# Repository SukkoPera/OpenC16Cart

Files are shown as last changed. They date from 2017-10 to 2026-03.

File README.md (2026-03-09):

# OpenC16Cart





OpenC16Cart is an Open Hardware 8/16/32/64 KB Cartridge for the Commodore 16, Plus/4 and the rest of the Commodore 264 family.

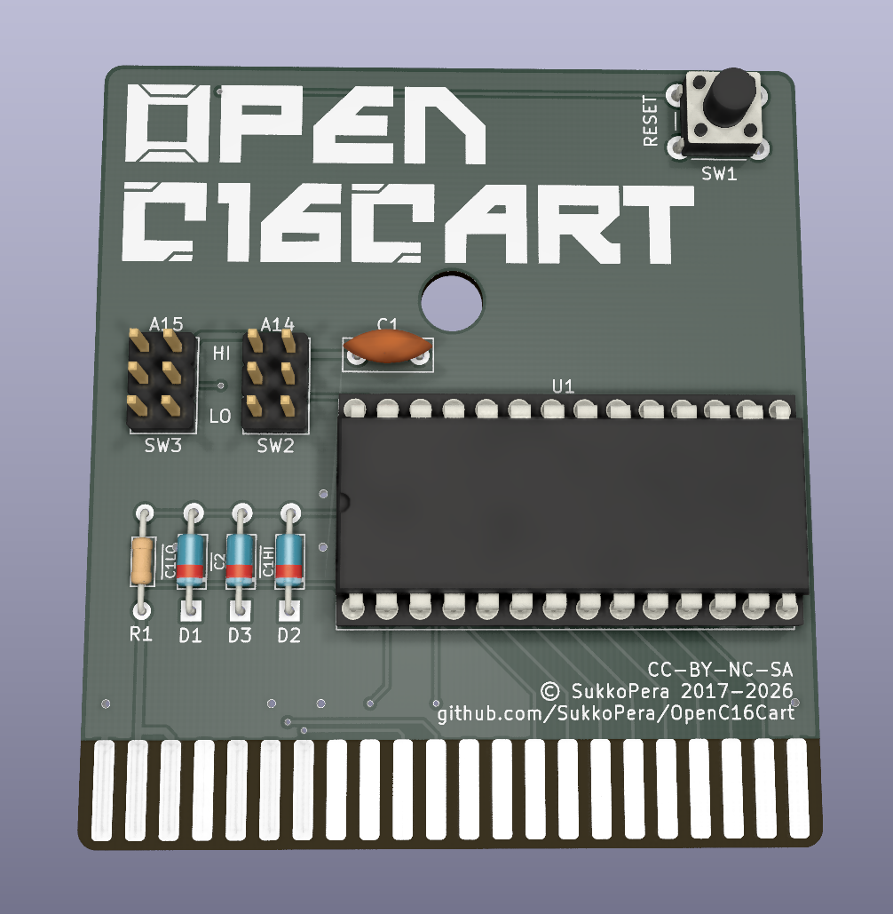
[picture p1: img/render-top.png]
Board


## Summary
> Like all the other Commodore 8-bit systems, the Plus/4 had a cartridge port for ROM-based software. Because the computer did not do well in the marketplace, however, very few were released. - Bo Zimmerman

One day I decided to fix my old Commodore 16. I found out about [Diag264](http://www.inchocks.co.uk/commodore/Diag264/) and, since I knew that C16 carts weren't exactly common (to this very day of 2026 I have never seen one "in the flesh"!), I was shocked to learn that [people are deliberately destroying genuine carts to use them as donors to build a Diag264](http://blog.tynemouthsoftware.co.uk/2014/03/commodore-264-c16-and-plus-4-diagnostic.html).

Since I had already built an [Open Hardware cartridge for the Commodore 64](https://github.com/SukkoPera/OpenC64Cart), I thought that one for the C16 could not be much different, and so this project was born.

Since I did not own a cartridge, I set out to find images of PCBs of real cartridges on the Net, only to find out that those are rare as well. In the end I found a couple of [top](https://github.com/SukkoPera/OpenC16Cart/blob/master/doc/inspiration-top.jpg)+[bottom](https://github.com/SukkoPera/OpenC16Cart/blob/master/doc/inspiration-bottom.jpg) images, and started to reverse engineer the design from those. With the help of [some service manuals](http://www.zimmers.net/anonftp/pub/cbm/schematics/computers/plus4/index.html), I came up with OpenC16Cart. I then expanded it to have the ability of using bigger (E(E))PROMs which could store multiple ROM images.

With V5, I even added the possibility of having a single-EEPROM 64 kB cartridge spanning both the C1 and C2 slots.

> [!IMPORTANT]
> V5 is a 44-pin cartridge. It is not compatible with a stock C16/+4. To use it, you will need a [Plus4MultiExpander](https://github.com/SukkoPera/Plus4MultiExpander) [^v4].

V5 was designed in order to fit into [TFW8b's Stumpy Cases](https://www.tfw8b.com/product/commodore-c64-stumpy-cartridge-case/), but the actual fitting has never been checked.

## Configuration
As of V5, OpenC16Cart might work in different modes. Ideally, the cartridge is used with a 64 kb EEPROM, in which case the following configurations will be available:

### 16 kB Mode
In 16 kB mode, you get 4 banks, which can be selected through appropriate placement of the SW2 and SW3 jumpers:

|Bank|SW3|SW2|ROM Area |
|----|---|---|---|
|0 |LO |LO |$0000-$3fff|
|1 |LO |HI |$4000-$7fff|
|2 |HI |LO |$8000-$bfff|
|3 |HI |HI |$c000-$ffff|

Note that the cartridge will respond to all C1 and C2 low/high slots. If this is unwanted, cut open JP1/2/3 accordingly (or do not mount D1/2/3). Also note there is no way to respond to a single C2 slot.

### 32 kB Mode
In 32 kB mode, SW2 must be placed in the `DIR` position and 2 banks will be available through manipulation of SW3:

|Bank|SW3|ROM Area |
|----|---|---|
|0 |LO |Low ROM: $0000-$3fff<br/>High ROM: $4000-$7fff|
|1 |HI |Low ROM: $8000-$bfff<br/>High ROM: $c000-$ffff|

As in 16 kB mode, you might want to play with the jumpers or diodes.

### 64 kB Mode
In 64 kB mode, both SW2 and SW3 must be placed in the `DIR` position and, obviously, only a single bank will be available.

|Bank|ROM Area |
|----|---|
|0 |C2 Low ROM: $0000-$3fff<br/>C2 High ROM: $4000-$7fff<br>C1 Low ROM: $8000-$bfff<br/>C1 High ROM: $c000-$ffff|

Note that **C2 goes first**.

## Releases
If you want to get this board produced, you are recommended to get [the latest release](https://github.com/SukkoPera/OpenC16Cart/releases) rather than the current git version, as the latter might be under development and is not guaranteed to be working.

Every release is accompanied by its Bill Of Materials (BOM) file and any relevant notes about it, which you are recommended to read carefully.

**I am not providing ready-to-use gerber files**. If all you want is **to get boards made, I would really appreciate if you did so [in a way that supports the project](#support-the-project)**.

## License
The OpenC16Cart documentation, including the design itself, is copyright &copy; SukkoPera 2019-2026 and is licensed under the [Creative Commons Attribution-NonCommercial-ShareAlike 4.0 International License](https://creativecommons.org/licenses/by-nc-sa/4.0/).

This documentation is distributed *as is* and WITHOUT ANY EXPRESS OR IMPLIED WARRANTIES whatsoever with respect to its functionality, operability or use, including, without limitation, any implied warranties OF MERCHANTABILITY, SATISFACTORY QUALITY, FITNESS FOR A PARTICULAR PURPOSE or infringement. We expressly disclaim any liability whatsoever for any direct, indirect, consequential, incidental or special damages, including, without limitation, lost revenues, lost profits, losses resulting from business interruption or loss of data, regardless of the form of action or legal theory under which the liability may be asserted, even if advised of the possibility or likelihood of such damages.

## Support the Project
If you want to get some boards manufactured, you can get them from PCBWay through this link:

PCB from PCBWay (https://www.pcbway.com/project/shareproject/OpenC16Cart_V5_Open_Hardware_8_16_32_Kb_Cartridge_for_the_Commodore_16_116_an_705564ed.html)

You get my gratitude and cheap, professionally-made and good quality PCBs, I get some credit that will help with this and [other projects](https://www.pcbway.com/project/member/shareproject/?bmbid=41100). You won't even have to worry about the various PCB options, it's all pre-configured for you!

Also, if you still have to register, [you can use this link](https://www.pcbway.com/setinvite.aspx?inviteid=41100) to get some bonus initial credit (and yield me some more).

You can also buy me a coffee if you want:



[^v4]: Although this *might* be amended at some point, that's why there currently is no V4, it was reserved for that.

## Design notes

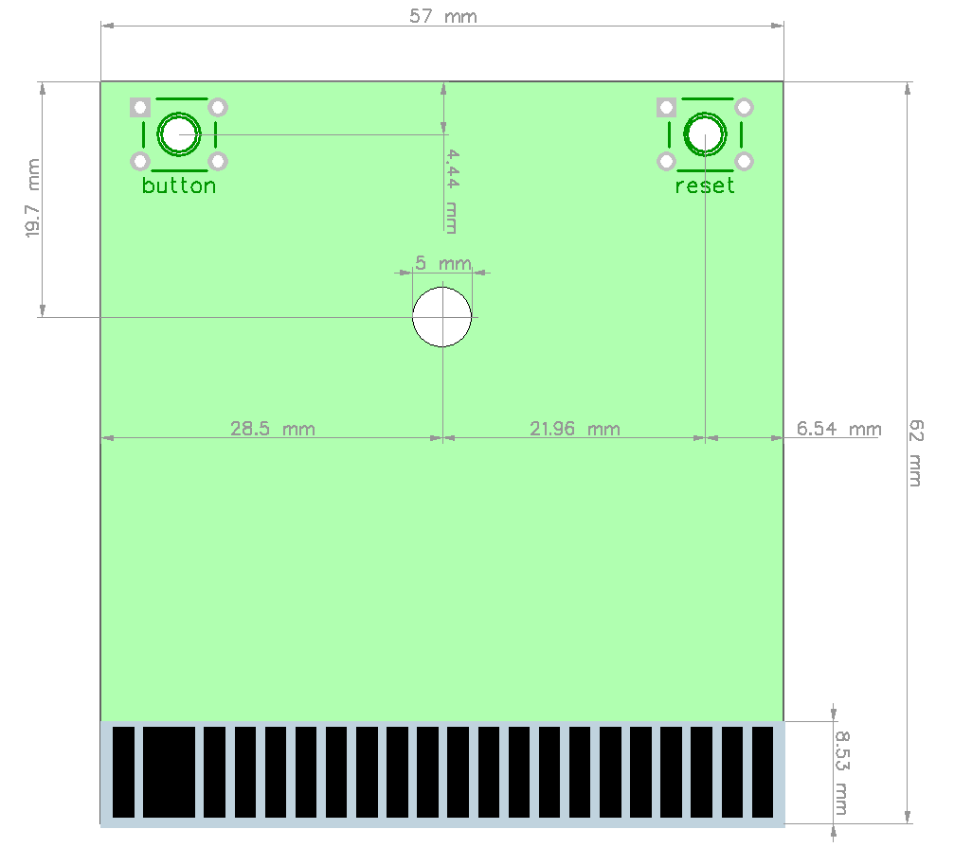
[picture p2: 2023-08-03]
doc/stumpy_case.png

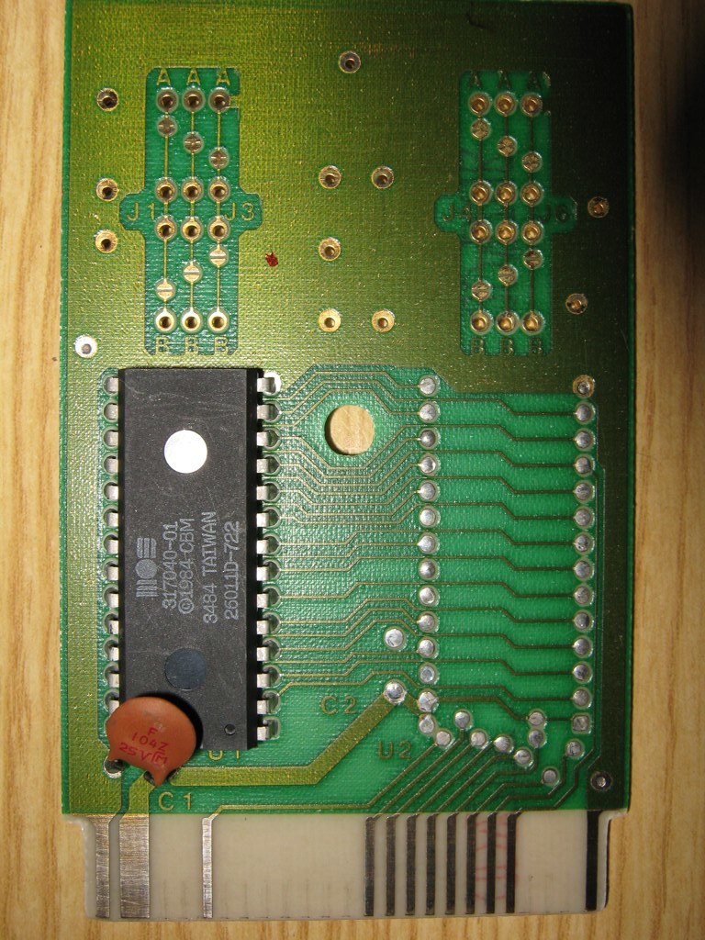
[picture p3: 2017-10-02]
doc/inspiration-top.jpg

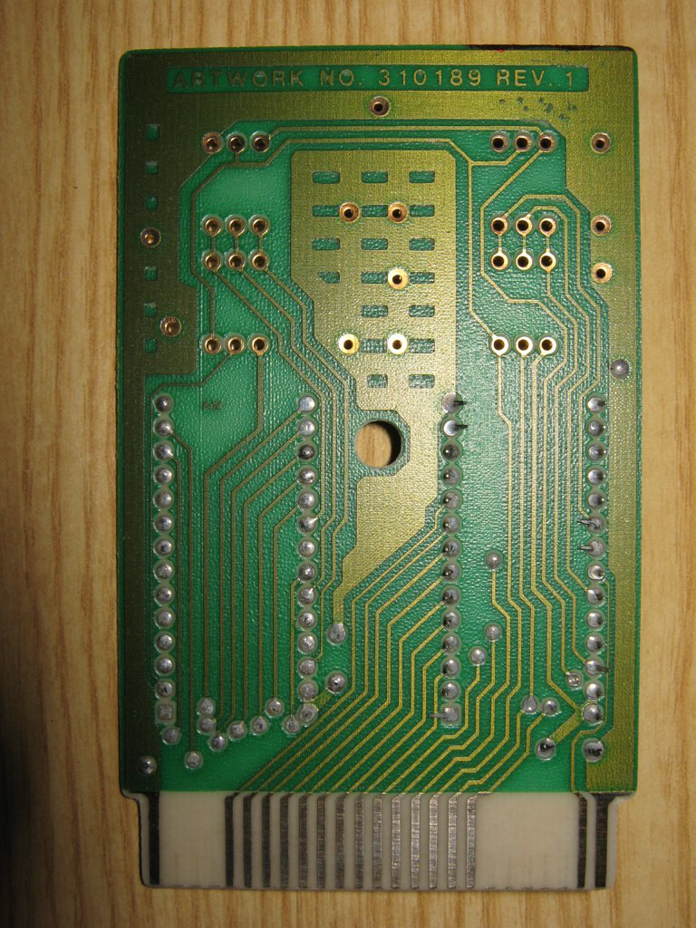
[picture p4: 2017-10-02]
doc/inspiration-bottom.jpg

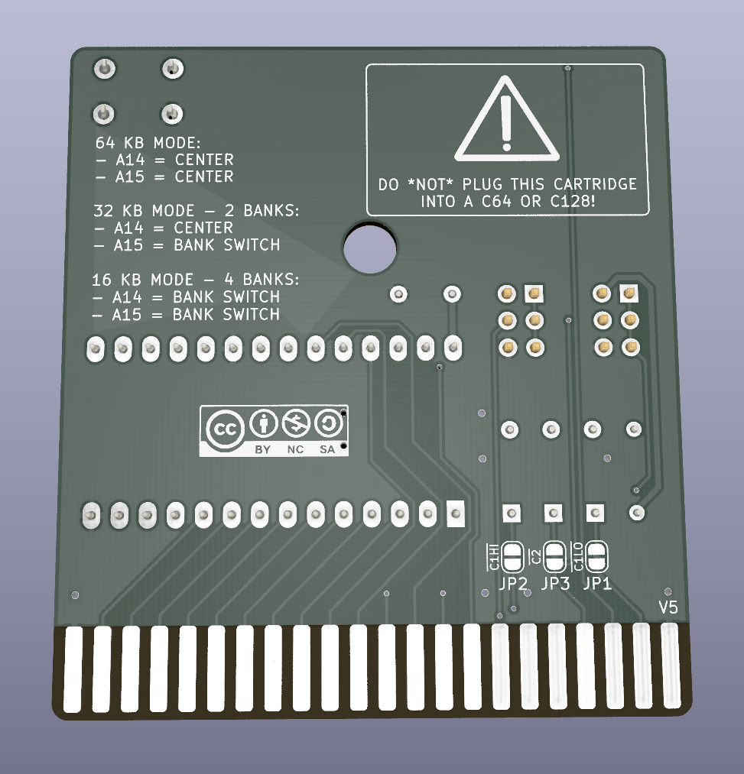
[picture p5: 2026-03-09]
img/render-bottom.png

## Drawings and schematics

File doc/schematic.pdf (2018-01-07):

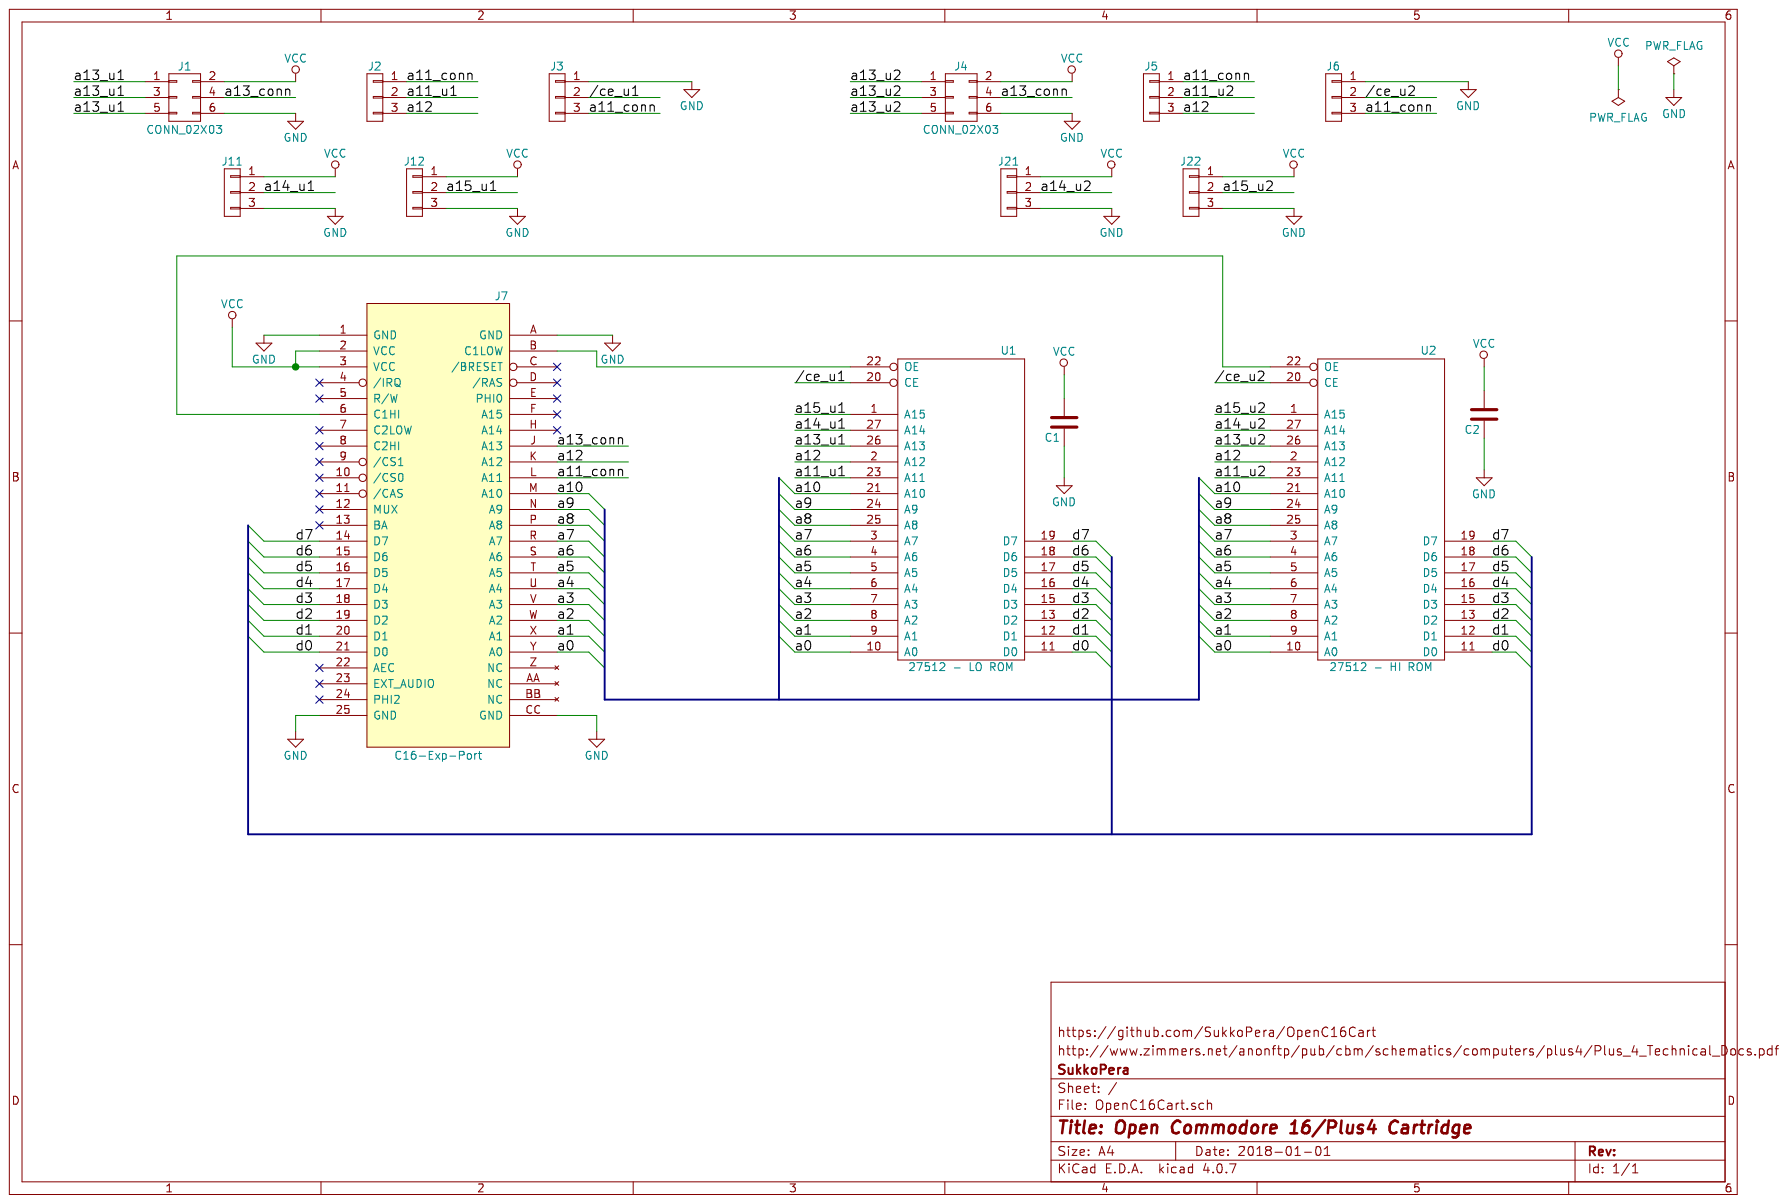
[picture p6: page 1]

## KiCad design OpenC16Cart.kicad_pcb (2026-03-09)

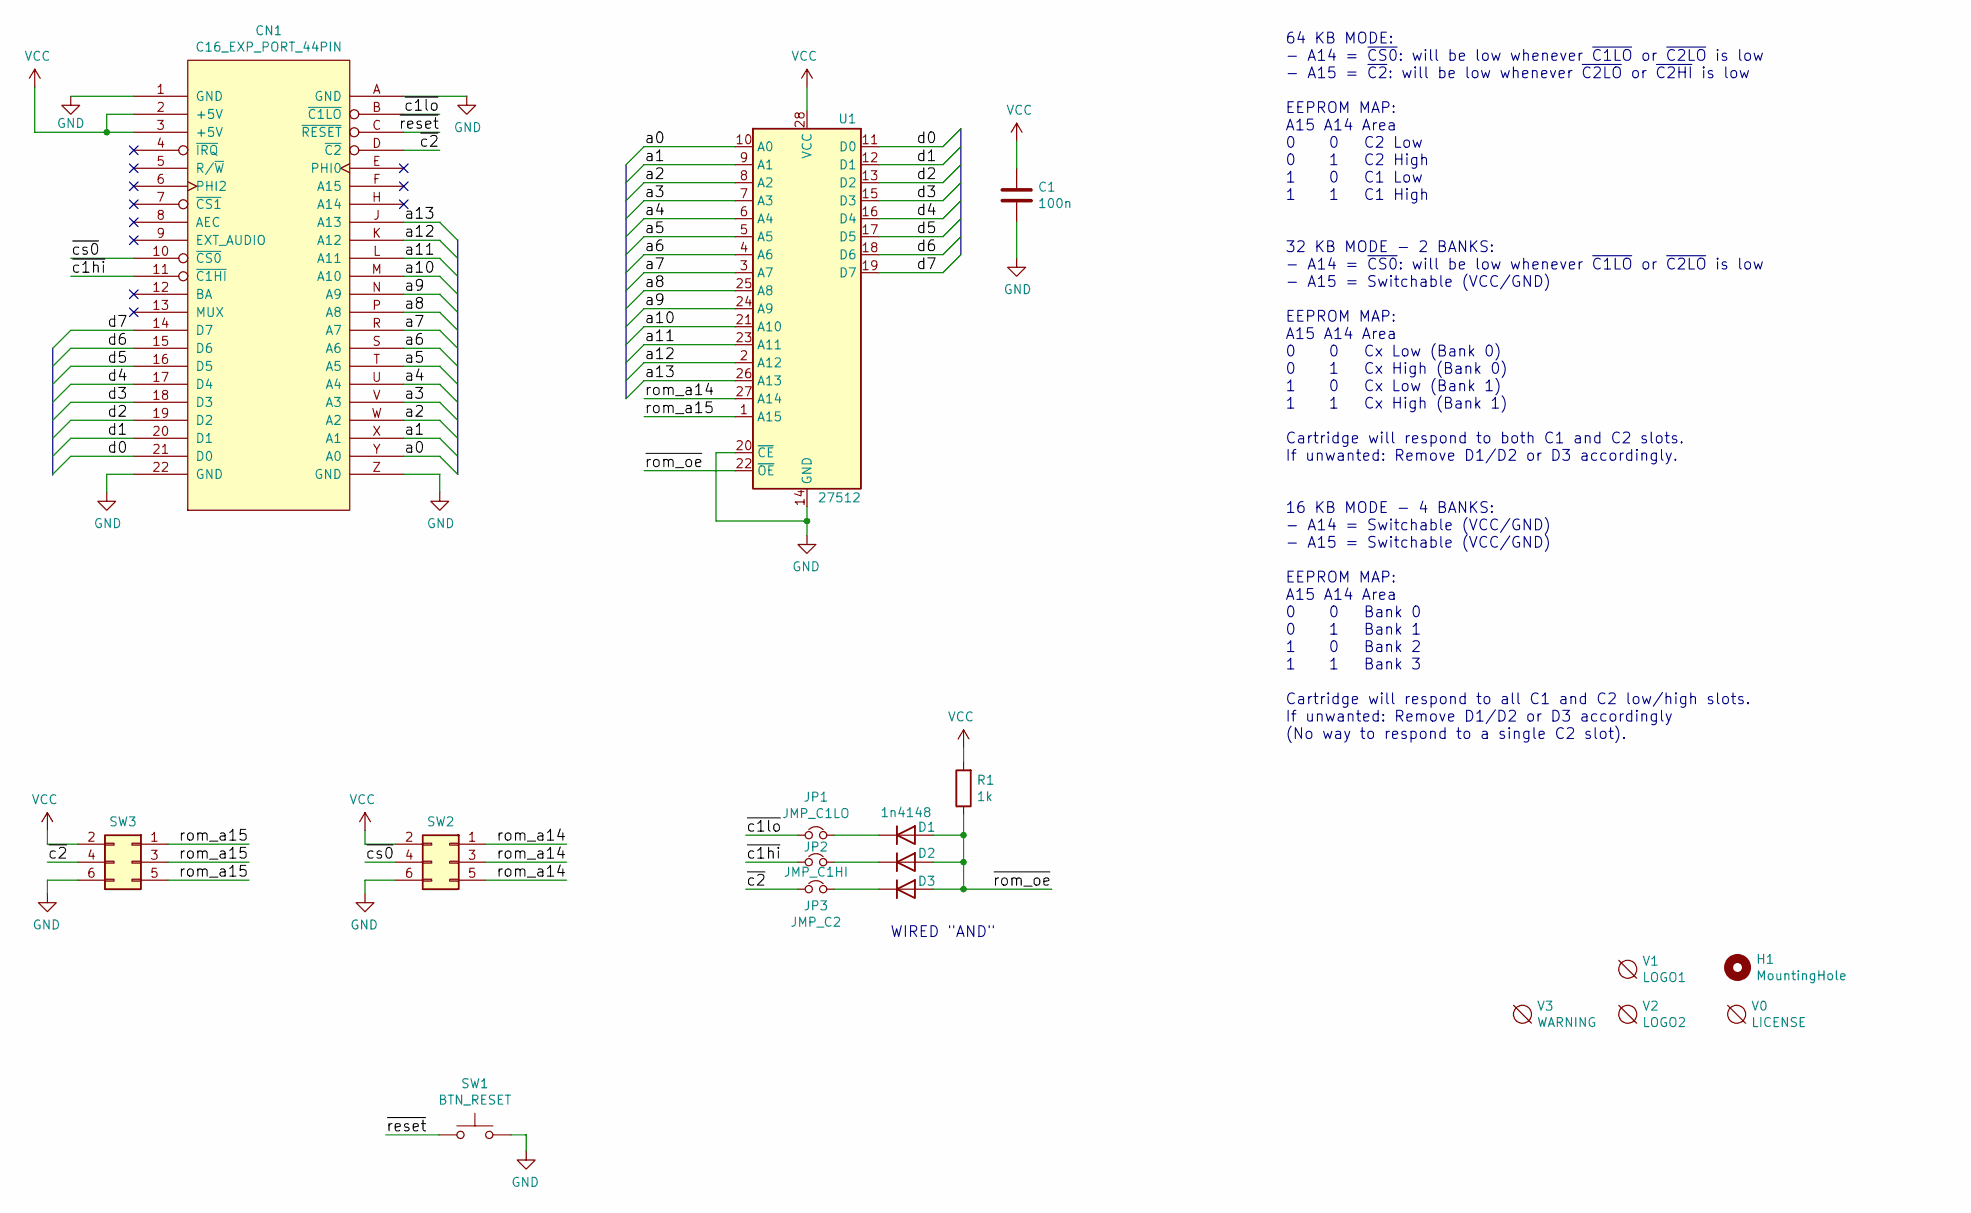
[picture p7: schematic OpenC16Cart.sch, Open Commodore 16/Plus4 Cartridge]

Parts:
C1: 100n; C_Disc_D7.0mm_W2.5mm_P5.00mm
CN1: C16_EXP_PORT_44PIN; C16-Exp-Port-44Pin
D1, D2, D3: 1n4148; D_DO-35_SOD27_P7.62mm_Horizontal
H1: MountingHole; MountingHole_5mm
JP1: JMP_C1LO; SolderJumper-2_P1.3mm_Bridged_RoundedPad1.0x1.5mm
JP2: JMP_C1HI; SolderJumper-2_P1.3mm_Bridged_RoundedPad1.0x1.5mm
JP3: JMP_C2; SolderJumper-2_P1.3mm_Bridged_RoundedPad1.0x1.5mm
R1: 1k; R_Axial_DIN0204_L3.6mm_D1.6mm_P7.62mm_Horizontal
SW1: BTN_RESET; SW_PUSH_6mm_H8mm
SW2, SW3: Conn_02x03_Odd_Even; PinHeader_2x03_P2.54mm_Vertical
U1: 27512; DIP-28_W15.24mm_Socket_LongPads
V0: LICENSE; cc_by_nc_sa
V1: LOGO1; logo1
V2: LOGO2; logo2
V3: WARNING; Logo_silk_warning_10x8.5mm

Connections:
/a0: CN1.Y (A0), U1.10 (A0)
/a1: CN1.X (A1), U1.9 (A1)
/a2: CN1.W (A2), U1.8 (A2)
/a3: CN1.V (A3), U1.7 (A3)
/a4: CN1.U (A4), U1.6 (A4)
/a5: CN1.T (A5), U1.5 (A5)
/a6: CN1.S (A6), U1.4 (A6)
/a7: CN1.R (A7), U1.3 (A7)
/a8: CN1.P (A8), U1.25 (A8)
/a9: CN1.N (A9), U1.24 (A9)
/a10: CN1.M (A10), U1.21 (A10)
/a11: CN1.L (A11), U1.23 (A11)
/a12: CN1.K (A12), U1.2 (A12)
/a13: CN1.J (A13), U1.26 (A13)
/d0: CN1.21 (D0), U1.11 (D0)
/d1: CN1.20 (D1), U1.12 (D1)
/d2: CN1.19 (D2), U1.13 (D2)
/d3: CN1.18 (D3), U1.15 (D3)
/d4: CN1.17 (D4), U1.16 (D4)
/d5: CN1.16 (D5), U1.17 (D5)
/d6: CN1.15 (D6), U1.18 (D6)
/d7: CN1.14 (D7), U1.19 (D7)
/rom_a14: SW2.1, SW2.3, SW2.5, U1.27 (A14)
/rom_a15: SW3.1, SW3.3, SW3.5, U1.1 (A15)
/~c1hi: CN1.11 (~C1HI), JP2.1
/~c1lo: CN1.B (~C1LO), JP1.1
/~c2: CN1.D (~C2), JP3.1, SW3.4
/~cs0: CN1.10 (~CS0), SW2.4
/~reset: CN1.C (~RESET), SW1.1
/~rom_oe: D1.2 (A), D2.2 (A), D3.2 (A), R1.1, U1.22 (~OE)
GND: C1.2, CN1.1 (GND), CN1.22 (GND), CN1.A (GND), CN1.Z (GND), SW1.2, SW2.6, SW3.6, U1.14 (GND), U1.20 (~CE)
unnamed: D1.1 (K), JP1.2
unnamed: D2.1 (K), JP2.2
unnamed: D3.1 (K), JP3.2
VCC: C1.1, CN1.2 (+5V), CN1.3 (+5V), R1.2, SW2.2, SW3.2, U1.28 (VCC)

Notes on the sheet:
WIRED "AND"
64 KB MODE: - A14 = ~CS0~: will be low whenever ~C1LO~ or ~C2LO~ is low - A15 = ~C2~: will be low whenever ~C2LO~ or ~C2HI~ is low EEPROM MAP: A15 A14 Area 0 0 C2 Low 0 1 C2 High 1 0 C1 Low 1 1 C1 High 32 KB MODE - 2 BANKS: - A14 = ~CS0~: will be low whenever ~C1LO~ or ~C2LO~ is low - A15 = Switcha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

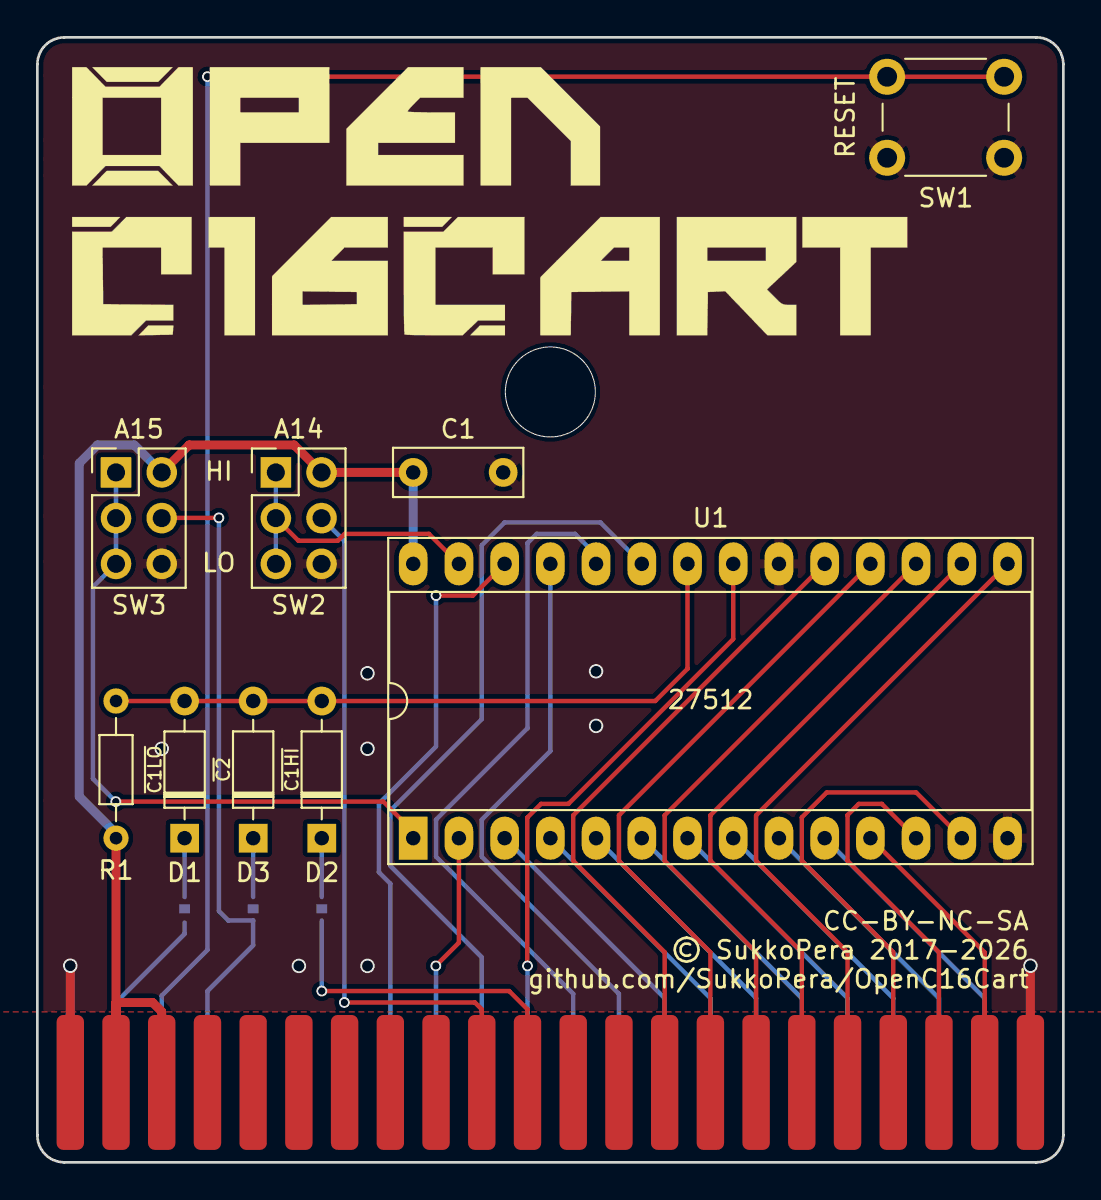
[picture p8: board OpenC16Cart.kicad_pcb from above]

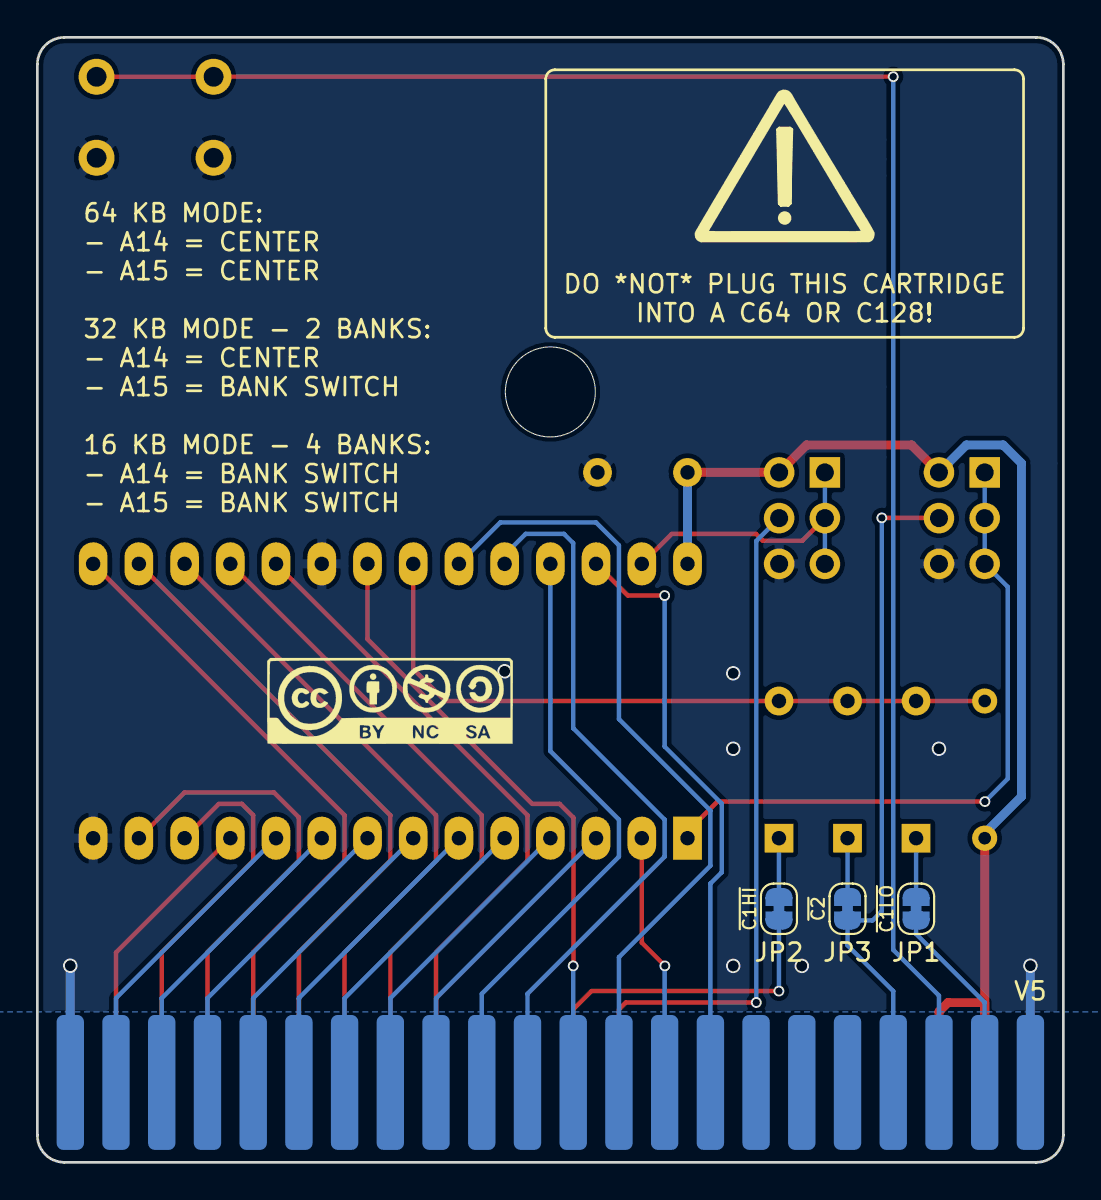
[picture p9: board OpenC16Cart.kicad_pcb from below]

Board: 2 copper layers, 57.0 x 62.5 mm, 18 parts (5 on the bottom side), 35 nets.

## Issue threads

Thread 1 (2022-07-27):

Run From C2 Bank

SukkoPera, 2022-07-27:
Jumpers should be added so that the Cart can run in the "C2" bank, as it is hardwired to "C1" at the moment.

This will allow Basic 7 to run without [the hack described here](https://plus4world.powweb.com/forum/41247#41375).

oO-cozy-Oo, 2025-01-11:
Is there any chance Jiffydos (16kb) can run from this pcb

SukkoPera, 2025-01-11:
> Is there any chance Jiffydos (16kb) can run from this pcb

Unfortunately no, JiffyDOS needs to run as the KERNAL ROM. You can use [this](https://github.com/SukkoPera/OpenRomSwitcher) to make it switchable.

oO-cozy-Oo, 2025-01-11:
Thank you just thought that if the diag264 rom works the jiffy might work

SukkoPera, 2025-01-12:
Diag264 has two separate versions, one to run in place of the KERNAL and one to run from an external cartridge.

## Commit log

2017-09-01 Add cart connector footprint
2017-09-01 Ignore more backup files and gerbers
2017-09-02 V2 is almost ready!
    [OpenC16Cart.kicad_pcb, OpenC16Cart.sch]
2017-09-02 Make board slightly larger
    [OpenC16Cart.kicad_pcb]
2017-09-02 Add OSHW logo
    [OpenC16Cart.kicad_pcb]
2017-09-29 Switch to C_0805_HandSoldering and rebuild whatever is needed
    [OpenC16Cart.kicad_pcb, OpenC16Cart.sch]
2017-09-30 Space edge connector pins 2.0mm apart
    [OpenC16Cart.kicad_pcb]
2017-09-30 Tighter soldermask
    [OpenC16Cart.kicad_pcb]
2017-09-30 Make top corners smooth
    [OpenC16Cart.kicad_pcb]
2017-09-30 Simplify ROM silkscreen
    [OpenC16Cart.kicad_pcb]
2017-09-30 Fix 3D models
    [OpenC16Cart.kicad_pcb]
2017-09-30 Bump version
    [OpenC16Cart.kicad_pcb]
2018-01-01 Minor tweaks'n'fixes
    [OpenC16Cart.kicad_pcb, OpenC16Cart.sch]
2018-01-07 Final touches for V3
    [OpenC16Cart.kicad_pcb]
2023-07-30 Port to KiCad 5 - NOT YET USABLE!
2023-07-30 Much better
    [OpenC16Cart.kicad_pcb, OpenC16Cart.sch]
2023-07-30 Experimental 16/32/64 KB version with 44-pin 2.54" connector
    [OpenC16Cart.kicad_pcb, OpenC16Cart.sch]
2023-07-30 Add logo
    [OpenC16Cart.kicad_pcb, OpenC16Cart.sch]
2023-08-03 Comply with Stumpy cases dimensions
    [OpenC16Cart.kicad_pcb]
2023-08-03 Add reset button
    [OpenC16Cart.kicad_pcb, OpenC16Cart.sch]
2023-08-03 Bigger logo and final touches
    [OpenC16Cart.kicad_pcb]
2023-08-03 Make hole compliant with Stumpy cases
    [OpenC16Cart.kicad_pcb, OpenC16Cart.sch]
2023-09-07 Fix R1 value and A14/15 labels
    [OpenC16Cart.kicad_pcb, OpenC16Cart.sch]
2023-09-10 Move components bottom left
    [OpenC16Cart.kicad_pcb]
2023-10-03 Switch to new pinout
    [OpenC16Cart.kicad_pcb, OpenC16Cart.sch]
2026-03-09 Ready for V5
    [OpenC16Cart.kicad_pcb, OpenC16Cart.sch]

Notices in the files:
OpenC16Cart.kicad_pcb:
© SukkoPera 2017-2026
